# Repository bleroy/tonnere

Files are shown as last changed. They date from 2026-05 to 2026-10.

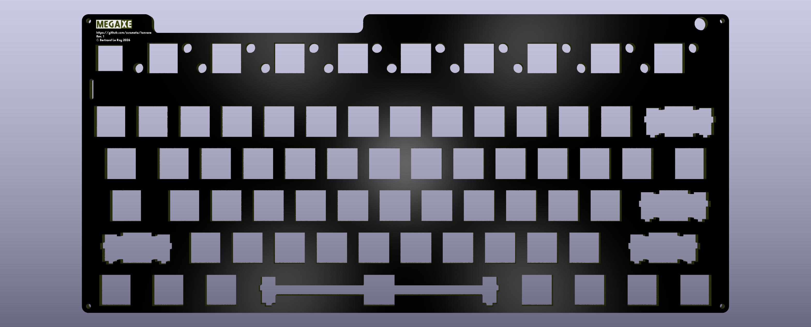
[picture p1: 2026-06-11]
keyboard/Media/MegaXE-plate.png

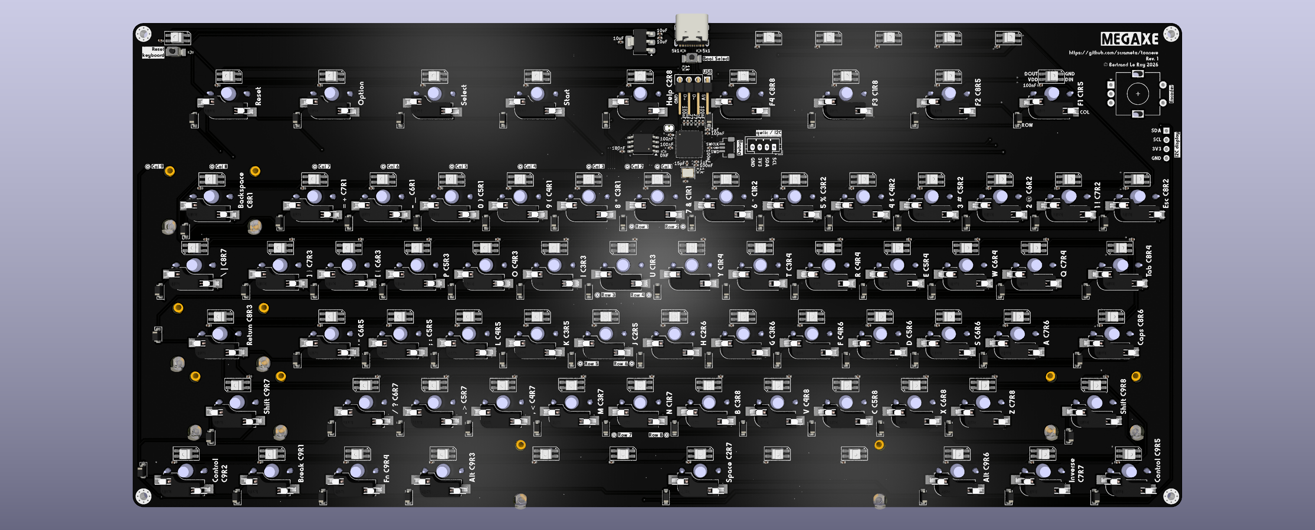
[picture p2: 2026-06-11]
keyboard/Media/MegaXE-keyboard-back.png

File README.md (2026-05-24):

## Project Tonnere

The EclaireXL was a partially open Atari XL FPGA implementation designed almost a decade ago. This project is intended to be a fully open community follow up version.

## Status

For now there is only a hardware design from which a physical board has been produced. The design goals of this are described below.

## Memory

3 independent banks of RAM from FPGA

- 512KB 16-bit wide 10ns SRAM (for VBXE)
- 2048KB 16-bit wide 10ns SRAM (primary Atari core)
- 32MB 16-bit wide SDRAM (secondary Atari core etc - for large memory expansions, cartridge emulation etc)

## Video output

- HDMI driven directly by FPGA
- Analog video driven by FPGA (3 pins/channel - ~8-bit/channel resolution) filtered/buffered by THS7316.
- NTSC in 480i or 480p, PAL in 576i or 576p
- Polyphasic and area-based scaler allowing 720p, 1080i etc

## Audio output

- PCM5102A DAC

## Audio input

- 12-bit ADC for PBI, SIO, 3.5mm left/right on STM microcontroller

## Joystick ports 1-4

- Directly connected to FPGA (via level shifters)
- Paddle support using STM ADC inputs

## Six USB ports

- 1 USB A internal for keyboard
- 3 USB A external for joystick, keyboard etc
- 1 USB C for power only (next to power switch)
- 1 rear USB C for STM32 DFU (to program it), or to be a mass-storage slave to a PC to copy data on.

## Atari peripheral emulator (ESP32 microcontroller/almost Fujinet)

- Wifi support
- Serial connection to STM32
- SPI master to FPGA (for DMA to RAM, faster than serial via STM)
- SIO pins (all)
- Audio out DAC goes to SIO audio in
- Slave to STM32
- Slave to Atari via SIO
- JTAG for debugging

## Firmware/control (STM32)

- SPI master to FPGA SPI flash chip (to program)
- Can restart FPGA
- SRAM port connected to FPGA (for DMA to Atari core RAM + RAM banks)
- IRQ from FPGA
- 4-bit external SD card interface
- SPI to internal micro SD card (will appear as IDE hard drive to Atari core)
- ADC for sampling (see audio in)
- Serial connection for communication for Atari peripheral emulator
- USB port + stack
- DFU mode for programming, can then program FPGA flash and ESP32 via serial (+BOOT etc).
- HDMI i2c link (to get mode support)
- PLL i2c link (6 programmable clocks for FPGA)
- SWD port for debugging
- UART port for debugging/expansion
- Will run menus etc, via DMA to Atari core (+ potentially framebuffer)

## Atari core (Cyclone 10 LP FPGA)

- Core Atari XL and Atari 800 support
- 2x/4x colour clock Antic/GTIA support
- VBXE
- PokeyMAX
- HDD via IDE emulation on microsd
- Turbo freezer
- Common cartridge banking logic (on RAM)

## Atari ports

- Left cartridge
- PBI with standard extensions (enabled/selected via jumper), 50 pin edge and 50 pin header option.
- SIO (with motor control, without 12V)
- Start/select/option/reset switch headers
- 4 joystick ports

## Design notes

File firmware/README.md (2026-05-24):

# Firmware for ESP32 and STM

## STM32

test project is using the basic HAL setup.

test usb project is using the THREADX and USBX.

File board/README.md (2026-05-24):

# Board status
## 0.51

| Component | Status | Comment |
| --- | --- | --- |
| Audio DAC |  🟢 | Played a multi-frequency sine wave fine |
| ESP32 |  🟢 | Ran simple pin toggler, also checked it appears on JTAG | 
| ESP32 audio DAC | ⚪ | |
| ESP32 WIFI | ⚪ | |
| FPGA |  🟢 | Working fine. Caution: Do not use clock input pins as outputs!  | 
| FPGA FLASH |  🟢 | Working fine. Only tested one IC.  | 
| HDMI port |  🟢 | Tested DVI video output  | 
| JOYSTICK DIR |  🟢 | Tested toggling pins |
| JOYSTICK PADDLES  | ⚪ |  |
| PLL1 |  🟢 | Programmed via I2C and checked they produce clocks |
| PLL2 |  🟢 | Programmed via I2C and checked they produce clocks |
| SDCARD(EXT) | ⚪ |  | 
| SDCARD(INT) | ⚪ |  | 
| SDRAM | ⚪ | Initial signs promising | 
| SRAM1 |  🟡 | Used input pins on FPGA, had to correct with a few wires  | 
| SRAM2 |  🟡 | Used input pins on FPGA, had to correct with a few wires  | 
| STM32 ADC | ⚪ |  | 
| STM32 CORE |  🟢 | Code running fine. SWD works. USART debug works. | 
| STM32 DFU |  🟡 | DFU slow to start due to PB5 connected to FPGA flash chip during boot  | 
| STM32 RTC |  ⚪ | | 
| STM32 FSMC |  🟢 | Checked basic SRAM access via FPGA from STM | 
| PBI |  🟢 | Tested toggling pins | 
| SIO |  🟡 | Tested toggling pins. Motor control did not go via level shifter. | 
| USB |  🟢 | Tested keyboard in all ports. STM needed patches hub (class + reconnect fix) |
| Video DAC |  🟡 | Single pin was too aggressive for sigma delta (very low oversampling). Too noisy. Added 2nd pin and used fixed patterns. Achieved 6-bit |

## 0.60

Not made yet...

## Key
| Symbol | Status |
| --- | --- |
| ⚪ | Not checked yet |
| 🔴 | Failed |
| 🟡 | Works with workaround |
| 🟢 | Passed |

Passed does not mean thoroughly checked...

<!--
| Feature A | ⚪ | Not checked yet |
| Feature C | 🟡 | Works with workaround |
| Feature D | 🟢 | Passed |
-->

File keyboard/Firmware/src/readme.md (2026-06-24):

# Decent MegaXE

*A 60% keyboard designed for the MegaXE FPGA retro computer*

* Keyboard Maintainer: [Bertrand Le roy](https://github.com/bleroy/3d-junkyard/blob/main/DecenTKL/)
* Hardware Supported: Decent MegaXE (RP2040 based)
* Hardware Availability: Custom built but open-source

Make example for this keyboard (after setting up your QMK build environment):

qmk compile -kb decent/megaxe -km default

Flashing example for this keyboard:

```
qmk flash -kb decent/megaxe -km default
```

See the [build environment setup](https://docs.qmk.fm/#/getting_started_build_tools) and the [make instructions](https://docs.qmk.fm/#/getting_started_make_guide) for more information. Brand new to QMK? Start with our [Complete Newbs Guide](https://docs.qmk.fm/#/newbs).

## Bootloader

Press the escape key or the button on the back of the Pi while connecting the keyboard.

## Special commands

[Control]+[Atari] + 1: Toggle RGB lighting
[Control]+[Atari] + Up: Next RGB effect
[Control]+[Atari] + Down: Previous RGB effect
[Control]+[Atari] + X: Change RGB hue
[Control]+[Atari] + S: Lower RGB brightness
[Control]+[Atari] + W: Raise RGB brightness
[Control]+[Atari] + Left: Lower RGB animation speed
[Control]+[Atari] + Right: Raise RGB animation speed

[Both shifts] + B: go into bootloader mode without unplugging the keyboard
[Both shifts] + \: delete configuration data

## Layout
```C
/*
    *      /─────/─────/─────/─────/─────/─────/─────/─────/─────/
    *     /F1   /F2   /F3   /F4   /Help /Start/Slect/Optin/Reset/
    *    /─────/─────/─────/─────/─────/─────/─────/─────/─────/
    * ┌───┬───┬───┬───┬───┬───┬───┬───┬───┬───┬───┬───┬───┬───────┐
    * │Esc│ 1!│ 2@│ 3#│ 4%│ 5%│ 6^│ 7&│ 8*│ 9(│ 0)│ - │ = │ Backsp│
    * ├───┴─┬─┴─┬─┴─┬─┴─┬─┴─┬─┴─┬─┴─┬─┴─┬─┴─┬─┴─┬─┴─┬─┴─┬─┴─┬─────┤
    * │ Tab │ Q │ W │ E │ R │ T │ Y │ U │ I │ O │ P │ [{│ ]}│  \| │
    * ├─────┴┬──┴┬──┴┬──┴┬──┴┬──┴┬──┴┬──┴┬──┴┬──┴┬──┴┬──┴┬──┴─────┤
    * │ Caps │ A │ S │ D │ F │ G │ H │ J │ K │ L │ ;:│ '"│  Enter │
    * ├──────┴─┬─┴─┬─┴─┬─┴─┬─┴─┬─┴─┬─┴─┬─┴─┬─┴─┬─┴─┬─┴─┬─┴────────┤
    * │ Shift  │ Z │ X │ C │ V │ B │ N │ M │ ,<│ .>│ /?│    Shift │
    * ├────┬───┴┬──┴─┬─┴───┴───┴───┴───┴───┴──┬┴───┼───┴┬────┬────┤
    * │Ctrl│ GUI│ Brk│                        │  ← │  ↑ │  ↓ │  → │
    * └────┴────┴────┴────────────────────────┴────┴────┴────┴────┘
*/

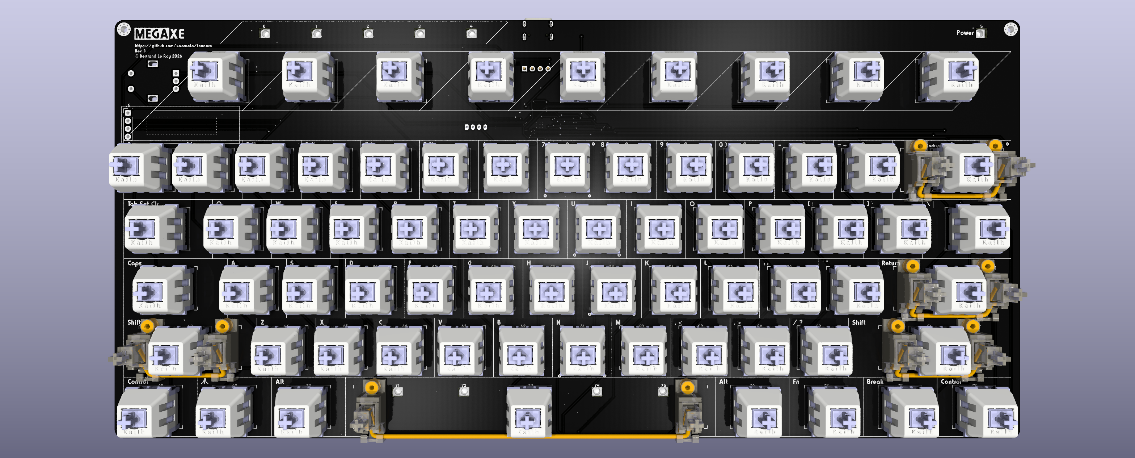
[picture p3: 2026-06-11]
keyboard/Media/MegaXE-keyboard.png

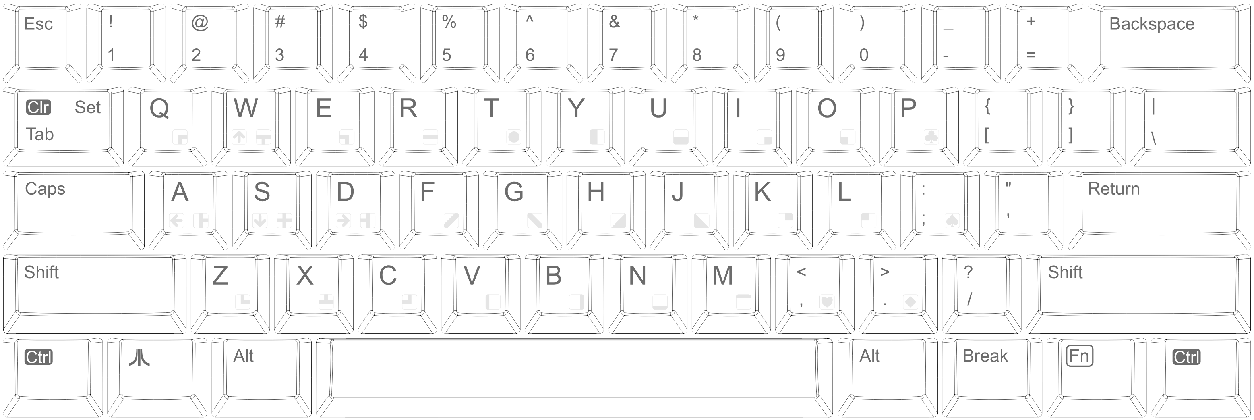
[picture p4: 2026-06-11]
keyboard/Media/Layout.png

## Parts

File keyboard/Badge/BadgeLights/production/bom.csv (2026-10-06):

Designator | Footprint | Quantity | Value | LCSC Part #
C24, C25, C26, C27, C28, C29, C30, C31 | 0805 | 8 | 100nF
D1, D2, D3, D4, D5, D6, D7, D8 | LED_WS2812B_PLCC4_5.0x5.0mm_P3.2mm | 8 | WS2812B
PRG | PinHeader_2x03_P2.54mm_Vertical | 1 | Conn_02x03_Odd_Even
PWR | PinHeader_1x02_P2.54mm_Vertical | 1 | Conn_01x02_Pin
QWIIC_2, QWIIC | PinHeader_1x04_P2.54mm_Vertical | 2 | Conn_01x04
R1 | R_Axial_DIN0207_L6.3mm_D2.5mm_P7.62mm_Horizontal | 1 | R
RGB OUT | PinHeader_1x03_P2.54mm_Vertical | 1 | Conn_01x03_Pin
U1 | DIP-8_W7.62mm | 1 | ATtiny85-20P

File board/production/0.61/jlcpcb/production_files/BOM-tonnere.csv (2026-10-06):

Comment | Designator | Footprint | LCSC | Quantity
0.1A | F2 | R_0603_1608Metric | C3760613 | 1
0.1uF | C10,C100,C101,C104,C105,C108,C109,C110,C112,C114,C115,C116,C118,C119,C120,C123,C126,C20,C26,C30,C32,C34,C35,C36,C39,C40,C44,C48,C52,C53,C55,C57,C62,C64,C65,C66,C70,C72,C73,C74,C75,C76,C78,C79,C8,C81,C83,C84,C86,C87,C88,C89,C90,C91,C92,C93,C94,C95,C96,C97,C99 | C_0603_1608Metric | C14663 | 61
0.5A | F1,F3,F4,F5,F6 | R_0603_1608Metric | C269152 | 5
100 | R46,R47 | R_0603_1608Metric | C22775 | 2
100k | R124,R125,R127,R132,R35,R51 | R_0603_1608Metric | C25803 | 6
100uF | C107,C122,C5,C54,C7,C80,C82,C85,C98 | C_1206_3216Metric | C883598 | 9
10CL040f484 | U33 | FBGA484_WIREBOND_A-2.40_INT | C1521940 | 1
10k | R101,R102,R103,R106,R107,R108,R110,R111,R113,R117,R118,R121,R122,R128,R24,R27,R28,R29,R31,R55,R60,R69,R70,R73,R74,R75,R99 | R_0603_1608Metric | C25804 | 27
10nF | C113,C12,C31,C42 | C_0603_1608Metric | C57112 | 4
10uF | C117,C14,C37,C45,C47,C61,C9 | C_0805_2012Metric | C15850 | 7
12K 1% | R42 | R_0603_1608Metric | C22790 | 1
12k | R133 | R_0603_1608Metric | C22790 | 1
16pF | C16,C17 | C_0603_1608Metric | C327125 | 2
18pF | C124,C125,C24,C25 | C_0603_1608Metric | C1647 | 4
1N4148WS | D6 | D_SOD-323 | C2128 | 1
1k | R104,R115,R16,R30,R36,R43,R48,R49,R50,R54,R56,R59,R67,R68,R7,R94,R98 | R_0603_1608Metric | C21190 | 17
1k47 0.1% | R83,R89,R91 | R_0603_1608Metric | C705739 | 3
1m | R1,R116,R23,R37,R39,R8,R9 | R_0603_1608Metric | C22935 | 7
1uF | C106,C28 | C_0805_2012Metric | C28323 | 2
1uF/DFE252012F-1R0M=P2 | L1,L2,L3 | L_1008_2520Metric | C435392 | 3
2.2nF | C2,C3 | C_0603_1608Metric | C1604 | 2
2.2uF | C1,C102,C103,C23,C27,C4,C6,C60,C63 | C_0603_1608Metric | C23630 | 9
20k | R105,R109,R114,R119 | R_0603_1608Metric | C4184 | 4
22 | RN10,RN7 | R_Array_Convex_4x0603 | C12008 | 2
22 | R112,R120,R123,R126,R130,R61,R71,R76,R77,R78,R84,R95,R96 | R_0603_1608Metric | C23345 | 13
22pF | C15,C18 | C_0603_1608Metric | C1653 | 2
22uF | C19,C41,C50,C59 | C_0805_2012Metric | C45783 | 4
24MHz | Y1,Y9 | Crystal_SMD_3225-4Pin_3.2x2.5mm | C5122304 | 2
25MHz | Y4,Y7 | Crystal_SMD_3225-4Pin_3.2x2.5mm | C337661 | 2
26k1 | R41,R52 | R_0603_1608Metric | C49196678 | 2
270 | RN1,RN2 | R_Array_Convex_4x0603 | C1966 | 2
2N7002 | Q3 | SOT-23 | C8545 | 1
2k7 | R13,R33,R34,R97 | R_0603_1608Metric | C13167 | 4
32.768KHz | Y3 | Crystal_SMD_3215-2Pin_3.2x1.5mm | C32346 | 1
32k4 | R32 | R_0603_1608Metric | C2998122 | 1
33pF | C67,C68,C69 | C_0603_1608Metric | C1663 | 3
4.7nF | C29,C33,C46,C51 | C_0603_1608Metric | C53987 | 4
4.7uF | C21,C22,C49 | C_0603_1608Metric | C19666 | 3
40k2 | R40 | R_0603_1608Metric | C2933218 | 1
470 | R17,R18,R19,R2,R6 | R_0603_1608Metric | C23179 | 5
47k | RN12,RN13,RN8 | R_Array_Convex_4x0603 | C102673 | 3
47k | R10,R20,R25,R26,R44,R45 | R_0603_1608Metric | C25819 | 6
47nF | C11,C13,C38,C43,C56,C58,C71,C77 | C_0603_1608Metric | C1622 | 8
49k9 0.1% | R85,R87,R90 | R_0603_1608Metric | C705780 | 3
4k7 | RN11,RN3,RN4,RN5,RN6,RN9 | R_Array_Convex_4x0603 | C1980 | 6
4k7 | R100,R11,R12,R129,R131,R14,R15,R3,R38,R58,R62,R63,R72,R92,R93 | R_0603_1608Metric | C23162 | 15
5k1 | R21,R22,R4,R5 | R_0603_1608Metric | C23186 | 4
6k04 0.1% | R82,R86,R88 | R_0603_1608Metric | C4109305 | 3
70@100MHz | FB1,FB2,FB3,FB4,FB5,FB6,FB7 | L_0805_2012Metric | C1012 | 7
73725-1180RLF | J21,J25,J26 | AMPHENOL_73725-1180RLF | C26235 | 3
74LVC1G17 | U11 | SOT-23-5 | C7836 | 1
75 | R64,R65,R66 | R_0603_1608Metric | C4275 | 3
750 0.1% | R79,R80,R81 | R_0603_1608Metric | C543637 | 3
820 | R53 | R_0603_1608Metric | C23253 | 1
8MHz | Y2 | Crystal_SMD_3225-4Pin_3.2x2.5mm | C2924617 | 1
AP2553AW6-7 | U34,U38,U39,U41 | SOT-26_L3.0-W1.6-P0.95-LS2.8-BL | C441827 | 4
AS4C16M16SA | U42 | TSOP-II-54_22.2x10.16mm_P0.8mm | C62246 | 1
ASE-27MHz | Y6 | Oscillator_SMD_Abracon_ASE-4Pin_3.2x2.5mm | C37635418 | 1
BCX51 | Q1 | SOT-89-3 | C475643 | 1
CONSOL | J24 | PinHeader_1x05_P2.54mm_Vertical | C225480 | 1
CR2032 | BT1 | BAT-TH_BS-05-A1BJ001 | C964752 | 1
Conn_01x01 | J7 | PinSocket_1x01_P2.54mm_Vertical | C492400 | 1
Conn_01x05 | J12 | PinHeader_1x05_P2.54mm_Vertical | C225480 | 1
DE15_Pins_HighDensity_MountingHoles | J4 | DB9-TH_XDDB-1518-0932 | C7498158 | 1
DMN2058U | Q2 | SOT-23 | C461001 | 1
ESP JTAG | J23 | IDC-Header_2x05_P2.54mm_Vertical | C5665 | 1
ESP PGM | J19 | PinHeader_1x05_P2.54mm_Vertical | C225480 | 1
ESP32-WROVER-E-N8R8 | U40 | WIFI-SMD_ESP32-WROVER-IE8MB | C529589 | 1
FPGA GPIO | J18 | PinSocket_1x07_P2.54mm_Vertical | C225482 | 1
FPGA JTAG | J22 | IDC-Header_2x05_P2.54mm_Vertical | C5665 | 1
FSUSB42UMX-TP | U17,U21 | XQFN-10_L1.8-W1.4-P0.40-TL | C42370490 | 2
HDD | Card1 | TF-SMD_472192001 | C164170 | 1
HDMI_A | J5 | HDMI-SMD_19P-P0.50-H-F | C138388 | 1
I2C | J27 | PinHeader_2x02_P2.54mm_Vertical | C225517 | 1
IS61WV204816BLL-10BLI | U36 | TF-BGA-48L_ISI | C1348743 | 1
IS61WV204816BLL-10BLI | U31 | TF-BGA-48L_ISI | C1349085 | 1
JA23331-HA6Q-4F | J28 | AUDIO-TH_JA23331-HA6Q-4F | C225739 | 1
LED_RED | D2,D3,D4,D5 | LED_0805_2012Metric | C84256 | 4
M25PX32-VMW | U27,U29 | SOIC-8_5.3x6.2mm_P1.27mm | C2944643 | 2
PBI Option | J8 | PinSocket_2x04_P2.54mm_Vertical | C225519 | 1
PCA9546APWR | U26 | TSSOP-16_L5.0-W4.4-P0.65-LS6.4-BL | C400705 | 1
PCM5102A | U19 | TSSOP-20_4.4x6.5mm_P0.65mm | C107671 | 1
PLT237/T10WH | U48 | CONN-TH_PLT237-T10WH | C17296340 | 1
SA-0-102-C04-0004-WP | SW1 | SW-TH_SA-0-102-C04-0004-WP | C22449118 | 1
SD-006M | Card2 | SD-SMD_SD-006M | C125615 | 1
SMAJ5.0A | D1 | D_SMA | C83329 | 1
SN74CB3T16211DGVR | U30,U32,U35,U37 | DGV56 | C2674751 | 4
SPI CFG | J15 | PinSocket_2x03_P2.54mm_Vertical | C225518 | 1
SPI SEL | J17 | PinHeader_1x03_P2.54mm_Vertical | C49257 | 1
STM BOOT0 | JP1 | PinHeader_1x03_P2.54mm_Vertical | C49257 | 1
STM GPIO | J9 | PinSocket_1x07_P2.54mm_Vertical | C225482 | 1
STM SWD | J10 | PinHeader_1x05_P2.54mm_Vertical | C225480 | 1
STM USART TTL | J14 | PinSocket_1x03_P2.54mm_Vertical | C49257 | 1
STM32F407ZGTx | U23 | LQFP-144_20x20mm_P0.5mm | C36869 | 1
Si5351A-B-GT | Y5,Y8 | MSOP-10_3x3mm_P0.5mm | C504891 | 2
THS7316DR | U25 | SOIC-8_L5.0-W4.0-P1.27-LS6.1-BL | C544774 | 1
TPD4E02B04DQA | U1,U12,U2,U3,U4,U43,U45,U46,U47 | USON-10_2.5x1.0mm_P0.5mm | C106794 | 9
TPD8E003DQDR | U10,U13,U14,U18,U24,U28,U5,U6,U7,U8,U9 | DQD8_1P2X0P4 | C2867469 | 11
TPS62903RPJR | U15,U16,U22 | VQFN-HR-9_L2.0-W1.5-P0.50-TL | C2866502 | 3
TYPE-C-31-M-19 | USB1,USB2 | USB-C-TH_TYPE-C-31-M-19 | C2689968 | 2
USB HS/FS | SW2 | SW-SMD_MST22D18G2 | C431544 | 1
USB2514B_Bi | U44 | QFN-36-1EP_6x6mm_P0.5mm_EP3.7x3.7mm | C16251 | 1
USB3300-EZK | U20 | QFN-32-1EP_5x5mm_P0.5mm_EP3.45x3.45mm | C108383 | 1
USB_A | J20 | USB_A_Molex_105057_Vertical | C586225 | 1
~ | J11,J16 | DualDSub9Male | C5431655 | 2

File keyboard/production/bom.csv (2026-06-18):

Designator | Footprint | Quantity | Value | LCSC Part #
C10, C100, C101, C102, C103, C104, C105, C106, C107, C108, C109, C11, C110, C111, C112, C113, C114, C115, C116, C117, C118, C119, C12, C120, C121, C123, C124, C125, C126, C127, C128, C129, C13, C130, C131, C132, C133, C134, C135, C136, C137, C138, C139, C140, C141, C142, C143, C144, C145, C146, C147, C148, C149, C150, C151, C152, C153, C154, C155, C4, C42, C6, C7, C75, C76, C77, C78, C79, C8, C80, C81, C82, C83, C84, C85, C86, C87, C88, C89, C9, C90, C91, C92, C93, C94, C95, C96, C97, C98, C99 | 0402 | 90 | 100nF | C1525
C14, C5 | 0402 | 2 | 1uF | C52923
C24, C25 | 0402 | 2 | 15pF | C1548
C27, C28, C43 | 0402 | 3 | 10uF | C15525
D101, D103, D105, D107, D109, D111, D113, D115, D119, D121, D123, D125, D127, D128, D129, D130, D131, D132, D133, D134, D135, D137, D139, D141, D143, D145, D147, D148, D17, D18, D19, D20, D21, D22, D23, D24, D25, D26, D27, D28, D29, D30, D31, D47, D49, D51, D53, D55, D57, D59, D61, D63, D65, D67, D69, D71, D73, D75, D77, D79, D81, D83, D85, D87, D89, D91, D93, D95, D97, D99 | D_SOD-123 | 70 | 1N4148W | C81598
D149, D150, D151, D152, D153, D154, D155, D156, D157, D158, D159, D160, D161, D162, D163, D164, D165, D166, D167, D168, D169, D170, D171, D172, D173, D174, D175, D176, D177, D178, D179, D180, D181, D182, D183, D184, D185, D186, D187, D188, D189, D190, D191, D192, D193, D194, D195, D197, D198, D199, D200, D201, D202, D203, D204, D205, D206, D207, D208, D209, D210, D211, D212, D213, D214, D215, D216, D217, D218, D219, D220, D221, D222, D223, D224, D225, D226, D227, D228, D229 | LED_SK6812MINI-E_3.2x2.8mm_P1.5mm_ReverseMount | 80 | SK6812MINI | C5378731
J5 | USB_C_Receptacle_C2765186 | 1 | USB_C_Receptacle_USB2.0_16P | C2765186
R26, R28 | 0402 | 2 | 27 | C138021
R30, R31, R32 | 0402 | 3 | 1k | C11702
R6, R7 | 0402 | 2 | 5k1 | C25905
SW10, SW11, SW12, SW13, SW14, SW15, SW16, SW17, SW19, SW20, SW21, SW22, SW23, SW24, SW25, SW26, SW27, SW28, SW29, SW30, SW31, SW32, SW33, SW34, SW35, SW36, SW37, SW38, SW39, SW40, SW41, SW42, SW43, SW44, SW45, SW46, SW47, SW48, SW49, SW50, SW51, SW52, SW53, SW54, SW55, SW56, SW57, SW58, SW59, SW61, SW64, SW65, SW66, SW67, SW68, SW70, SW71, SW72, SW73, SW74, SW76, SW77, SW78, SW79, SW80 | Kailh_socket_MX_1-00U | 65 | MX | C41430893
SW18 | Kailh_socket_MX_6-25U | 1 | MX | C41430893
SW2 | TactileSwitch | 1 | SW_BOOT_SELECT | C720477
SW3 | TactileSwitch | 1 | SW_RESET | C720477
SW62, SW63, SW69, SW75 | Kailh_socket_MX_2-00U | 4 | MX | C41430893
U4 | SOT-223-3_TabPin2 | 1 | NCP1117-3.3 | C6186
U7 | QFN-56-1EP_7x7mm_P0.4mm_EP3.2x3.2mm | 1 | RP2040 | C2040
U9 | SOIC-8_5.3x5.3mm_P1.27mm | 1 | W25Q128JVS | C97521
X1 | Crystal_SMD_Abracon_ABM8AIG-4Pin_3.2x2.5mm | 1 | 12MHz | C9002

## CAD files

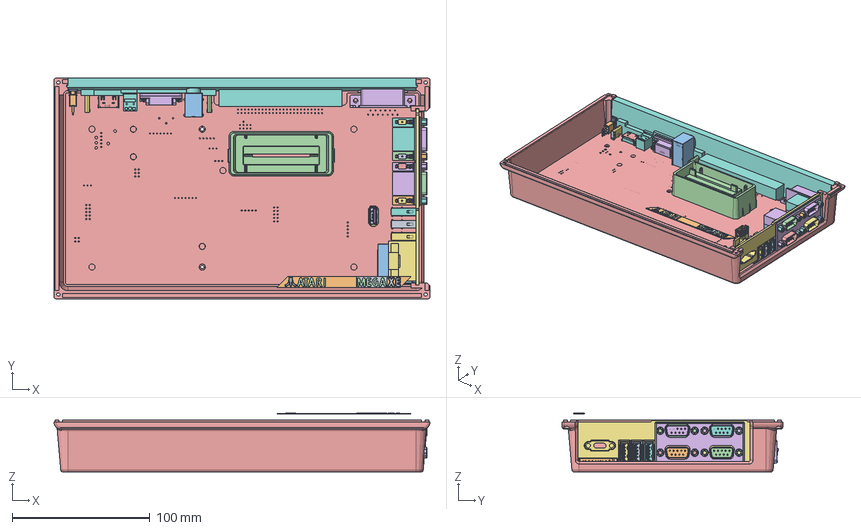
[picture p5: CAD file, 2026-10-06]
enclosure/MegaXE_case.FCStd
272.8 x 160.0 x 42.5 mm
Badge_copper
Badge_soldermask
Badge_soldermask001
Badge_PCB
Case bottom
Joystick port filler
Right ports panel
Back ports panel
SW-TH_SA-0-102-C04-0004-WP002
SW-TH_SA-0-102-C04-0004-WP003
SW-TH_SA-0-102-C04-0004-WP004
USB-C-TH_TYPE-C-31-M-004
USB-C-TH_TYPE-C-31-M-005
USB-C-TH_TYPE-C-31-M-006
USB-C-TH_TYPE-C-31-M-007
USB-C-TH_TYPE-C-31-M-008
USB-C-TH_TYPE-C-31-M-009
USB-C-TH_TYPE-C-31-M-010
USB-C-TH_TYPE-C-31-M-011
USB-C-TH_TYPE-C-31-M-012
USB-C-TH_TYPE-C-31-M-013
USB-C-TH_TYPE-C-31-M-014
USB-C-TH_TYPE-C-31-M-015
USB-C-TH_TYPE-C-31-M-016
USB-C-TH_TYPE-C-31-M-017
USB-C-TH_TYPE-C-31-M-018
USB-C-TH_TYPE-C-31-M-019
USB-C-TH_TYPE-C-31-M-020
SD-SMD_SD-006M002
SD-SMD_SD-006M003
SD-SMD_SD-006M004
SD-SMD_SD-006M005
SD-SMD_SD-006M006
SD-SMD_SD-006M007
SD-SMD_SD-006M008
DSUB-TH_HYC33-VGA18A-158
DSUB-TH_HYC33-VGA18A-159
DSUB-TH_HYC33-VGA18A-160
DSUB-TH_HYC33-VGA18A-161
DSUB-TH_HYC33-VGA18A-162
DSUB-TH_HYC33-VGA18A-163
DSUB-TH_HYC33-VGA18A-164
DSUB-TH_HYC33-VGA18A-165
DSUB-TH_HYC33-VGA18A-166
DSUB-TH_HYC33-VGA18A-167
DSUB-TH_HYC33-VGA18A-168
DSUB-TH_HYC33-VGA18A-169
DSUB-TH_HYC33-VGA18A-170
DSUB-TH_HYC33-VGA18A-171
DSUB-TH_HYC33-VGA18A-172
DSUB-TH_HYC33-VGA18A-173
DSUB-TH_HYC33-VGA18A-174
DSUB-TH_HYC33-VGA18A-175
DSUB-TH_HYC33-VGA18A-176
DSUB-TH_HYC33-VGA18A-177
DSUB-TH_HYC33-VGA18A-178
DSUB-TH_HYC33-VGA18A-179
DSUB-TH_HYC33-VGA18A-180
DSUB-TH_HYC33-VGA18A-181
DSUB-TH_HYC33-VGA18A-182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

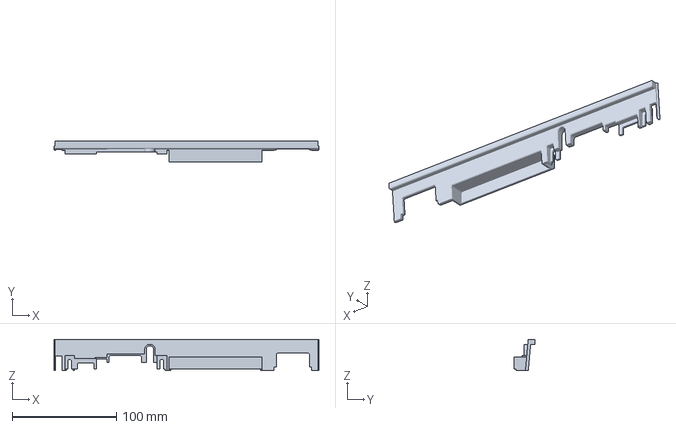
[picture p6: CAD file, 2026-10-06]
enclosure/MegaXE-Case-Back-panel.3mf
254.4 x 20.6 x 30.0 mm

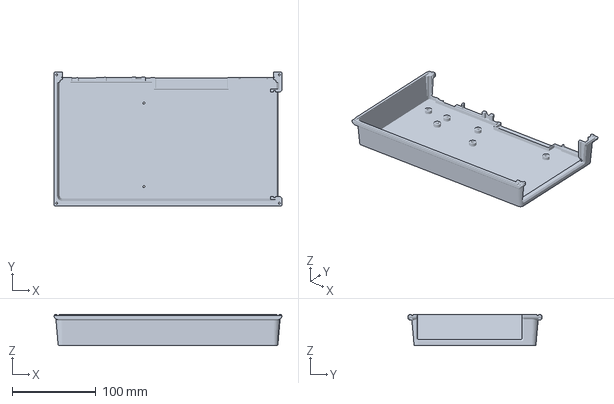
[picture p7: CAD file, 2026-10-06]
enclosure/MegaXE-Case-Bottom.3mf
272.8 x 160.0 x 37.5 mm

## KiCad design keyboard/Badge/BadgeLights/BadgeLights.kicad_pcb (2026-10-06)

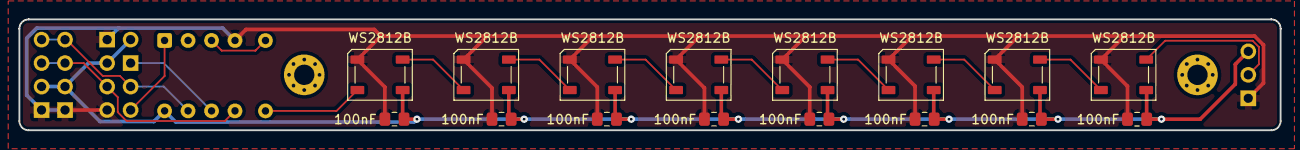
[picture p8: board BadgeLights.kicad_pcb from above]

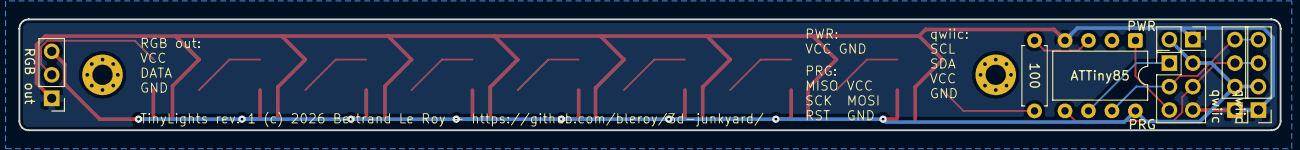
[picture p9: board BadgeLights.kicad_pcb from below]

Board: 2 copper layers, 136.5 x 12.0 mm, 25 parts (7 on the bottom side), 16 nets.

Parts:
C24, C25, C26, C27, C28, C29, C30, C31: 100nF; C_0805_2012Metric_Pad1.18x1.45mm_HandSolder
D1, D2, D3, D4, D5, D6, D7, D8: WS2812B; LED_WS2812B_PLCC4_5.0x5.0mm_P3.2mm
H1, H2: MountingHole_Pad; MountingHole_2.2mm_M2_Pad_Via
PRG: Conn_02x03_Odd_Even; PinHeader_2x03_P2.54mm_Vertical
PWR: Conn_01x02_Pin; PinHeader_1x02_P2.54mm_Vertical
R1: R; R_Axial_DIN0207_L6.3mm_D2.5mm_P7.62mm_Horizontal
RGB out: Conn_01x03_Pin; PinHeader_1x03_P2.54mm_Vertical
U1: ATtiny85-20P; DIP-8_W7.62mm
qwiic: Conn_01x04; PinHeader_1x04_P2.54mm_Vertical
qwiic#2: Conn_01x04; PinHeader_1x04_P2.54mm_Vertical

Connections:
+5V: C24.1, C25.1, C26.1, C27.1, C28.1, C29.1, C30.1, C31.1, D1.1 (VDD), D2.1 (VDD), D3.1 (VDD), D4.1 (VDD), D5.1 (VDD), D6.1 (VDD), D7.1 (VDD), D8.1 (VDD), PRG.2, PWR.2, RGB out.3, U1.8 (VCC), qwiic.2, qwiic#2.2
GND: C24.2, C25.2, C26.2, C27.2, C28.2, C29.2, C30.2, C31.2, D1.3 (VSS), D2.3 (VSS), D3.3 (VSS), D4.3 (VSS), D5.3 (VSS), D6.3 (VSS), D7.3 (VSS), D8.3 (VSS), PRG.6, PWR.1, RGB out.1, U1.4 (GND), qwiic.1, qwiic#2.1
unnamed: D1.4 (DIN), R1.2
unnamed: D1.2 (DOUT), D2.4 (DIN)
unnamed: D2.2 (DOUT), D3.4 (DIN)
unnamed: D3.2 (DOUT), D4.4 (DIN)
unnamed: D4.2 (DOUT), D5.4 (DIN)
unnamed: D5.2 (DOUT), D6.4 (DIN)
unnamed: D6.2 (DOUT), D7.4 (DIN)
unnamed: D7.2 (DOUT), D8.4 (DIN)
unnamed: D8.2 (DOUT), RGB out.2
unnamed: PRG.1, U1.6 (PB1)
unnamed: PRG.3, U1.7 (PB2), qwiic.4, qwiic#2.4
unnamed: PRG.4, U1.5 (AREF/PB0), qwiic.3, qwiic#2.3
unnamed: PRG.5, U1.1 (~RESET/PB5)
unnamed: R1.1, U1.3 (XTAL2/PB4)

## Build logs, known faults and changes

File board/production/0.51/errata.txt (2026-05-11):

Power:
Power switch connects 5V to GND when off!
USB DFU:
STM PB5 MOSI messes up DFU:
i) Free PA7 by moving the ADC input to PB0.
ii) Free PB5 by moving SPI from PB5 to PA7.
iii) Potentially we need pull downs on PB5, PA10, PB11 (or gnd them). To be tested if it 'just works' or not.
iv) U32 D9/D10 are on input only FPGA pins! So we lose 1MB of SRAM without patching it. AA12/AB12. Spare pins for respin: T10, R14, T13. Bodge: Use A20 (unused) from both SRA chips for D9/D10.
v) G2 (DAC G) is also on an input only pin. Move to F1? Bodge: Use FPGA GPIO on bus switch side (+ cut trace)
vi) DAC is a bit noisy with only one pin per channel and sigma delta. Add a capacitor at a minimum, though most likely use a second pin at a lower level (part R2R and part pattern based or sigma delta - TBD). (Actually will go with 3 pins...)
vii) SIO.MOTOR does not go via the level shifter (so does not turn on). Also transistor is not fully on but is enough for 100mA which is within SIO specs I think.
viii) D2 is back to front, so STM reset on connect does not work.
ix) Reset button is not connected to header

Layout:
a) Move power switch and power in slightly further apart.
b) Add solder pads to DB9s
c) Add a power LED or at least an LED header
d) Cartridge footprint is wrong (pin placement width)

To consider:
a) USB power ic and VBUS plumbing
b) USB HS PHY

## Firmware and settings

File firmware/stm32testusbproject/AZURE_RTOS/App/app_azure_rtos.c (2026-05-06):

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

/* Includes ------------------------------------------------------------------*/

#include "app_azure_rtos.h"

/* USER CODE BEGIN Includes */

#include "main.h"
#include "logger.h"
#include "thread_toggle.h"
#include "thread_memtest.h"

#include "si5351_modes.h"
#include "i2c_switch.h"

/* USER CODE END Includes */

static UCHAR tx_byte_pool_buffer[TX_APP_MEM_POOL_SIZE];
static TX_BYTE_POOL tx_app_byte_pool;

static UCHAR  ux_host_byte_pool_buffer[UX_HOST_APP_MEM_POOL_SIZE];
static TX_BYTE_POOL ux_host_app_byte_pool;

/**
  * @brief  Define the initial system.
  * @param  first_unused_memory : Pointer to the first unused memory
  * @retval None
  */
VOID tx_application_define(VOID *first_unused_memory)
{
  VOID *memory_ptr;

  if (tx_byte_pool_create(&tx_app_byte_pool, "Tx App memory pool", tx_byte_pool_buffer, TX_APP_MEM_POOL_SIZE) != TX_SUCCESS)
  {
  }
  else
  {
    memory_ptr = (VOID *)&tx_app_byte_pool;

    if (App_ThreadX_Init(memory_ptr) != TX_SUCCESS)
    {
    }

  }

  if (tx_byte_pool_create(&ux_host_app_byte_pool, "Ux App memory pool", ux_host_byte_pool_buffer, UX_HOST_APP_MEM_POOL_SIZE) != TX_SUCCESS)
  {
  }
  else
  {
    /* USER CODE BEGIN UX_HOST_Byte_Pool_Success */

    logger_init();

    /* USER CODE END UX_HOST_Byte_Pool_Success */

    memory_ptr = (VOID *)&ux_host_app_byte_pool;

    if (MX_USBX_Host_Init(memory_ptr) != UX_SUCCESS)
    {
    }

    /* USER CODE BEGIN MX_USBX_Host_Init_Success */
    thread_toggle_init();
 //   thread_memtest_init();
    log_printf("Init SI5351\r\n");
    HAL_GPIO_WritePin(STM_I2CRESET_GPIO_Port, STM_I2CRESET_Pin, GPIO_PIN_SET);
    pca9546_select(2);
    si5351_init();                          // once after power-on
    si5351_apply_mode(SI5351_MODE_720_PAL); // call whenever mode changes
    pca9546_select(3);
    si5351_init();                          // once after power-on
    si5351_apply_mode(SI5351_MODE_720_PAL); // call whenever mode changes
    log_printf("Init SI5351 DONE\r\n");

    /* USER CODE END MX_USBX_Host_Init_Success */
  }

}

/* USER CODE BEGIN  0 */
extern I2C_HandleTypeDef hi2c1;
void si5351_write(uint8_t reg, uint8_t val)
{
    uint8_t buf[2] = { reg, val };
    HAL_I2C_Master_Transmit(&hi2c1, 0xc0, &buf, 2, HAL_MAX_DELAY);
}
extern void pca9546_write(uint8_t addr, uint8_t val)
{
    HAL_I2C_Master_Transmit(&hi2c1, addr, &val, 1, HAL_MAX_DELAY);
}


/* USER CODE END  0 */

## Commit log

2026-05-07 Added documentation for i2c switch and SI5351 clock programming. Also a document on how the clocks were dediced and how to set it up with a library (not used in the end)
2026-05-11 Added note on reset button (goes to level shifter ... then nowhere!)
2026-05-24 0.60 (not final). Fix errata from 0.51. Added USB2 phy.
    [Microcontroller.kicad_sch, atariinterfaces.kicad_sch, audio.kicad_sch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]
2026-05-24 Added notes on some 0.60 changes: 3 bit dac, USB2, USART pins removed (now UART), reset added to header. Also fixed a note on the joysticks going to STM, that was changed prior to 0.51.
2026-05-24 First notes on board bring up status
2026-05-24 Moved bring up to the main board readme
2026-06-11 Keyboard and plate
    [MegaXE-keyboard.kicad_sch, MegaXE-plate.kicad_pcb, bom.csv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]
2026-06-17 Production file fixes for the keyboard PCB
    [MegaXE-keyboard.kicad_sch, bom.csv, controller.kicad_sch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]
2026-09-07 A small board to backlight the case's badge
    [BadgeLights.kicad_pcb, BadgeLights.kicad_sch, bom.csv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]
2026-09-27 Created 0.61 production files using jlcpcb kicad plugin
    [BOM-tonnere.csv, Microcontroller.kicad_sch, atariinterfaces.kicad_sch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]
2026-10-03 Added Alien to silkscreen
    [tonnere.kicad_pcb]
2026-10-03 Use the jlcpcb plugin output directly
    [BOM-tonnere.csv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]
2026-10-06 Update badgelight board for I2C out
    [BadgeLights.kicad_pcb, bom.csv, designators.csv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]
2026-10-06 Motherboard enclosure rev. 2
    Modified for optical audio out and stacked audio jacks
    [MegaXE-Case-Back-panel.3mf, MegaXE-Case-Bottom.3mf, MegaXE_case.FCStd]

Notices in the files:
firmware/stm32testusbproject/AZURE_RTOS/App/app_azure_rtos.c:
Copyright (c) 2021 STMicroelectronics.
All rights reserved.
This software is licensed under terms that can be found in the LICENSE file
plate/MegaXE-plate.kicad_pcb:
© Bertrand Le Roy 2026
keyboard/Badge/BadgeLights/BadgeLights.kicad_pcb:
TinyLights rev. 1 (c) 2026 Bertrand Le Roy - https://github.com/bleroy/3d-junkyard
